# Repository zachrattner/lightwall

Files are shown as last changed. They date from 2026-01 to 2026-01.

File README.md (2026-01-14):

# Lightwall: An Installation That Sees You

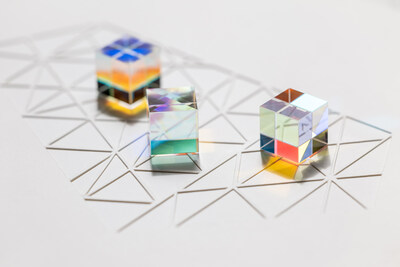
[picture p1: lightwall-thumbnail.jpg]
Lightwall


# Introduction
Created by artist [Rita Sus](https://emit-light.com), technologist [Zach Rattner](https://zachrattner.com), and students from [California State Fullerton](https://www.fullerton.edu/), Lightwall places the visitor at the center of the artwork's unfolding behavior. Rather than generating images or automating creativity, the piece uses AI as an expressive instrument: one that senses, reacts, and performs in the room.

Built from rotating prisms, custom electronics, and precisely controlled lighting, Lightwall transforms motion and speech into evolving patterns of color and sound. Inside the structure, more than a dozen microcontrollers coordinate sensors, prisms, motors, and sound cues, all synchronized with a live AI system running locally on a single Mac mini. This compact but powerful architecture allows the installation to observe, interpret, and respond instantly, producing an encounter that feels less like digital technology and more like a sensitive, perceptive presence.

# Running Lightwall

## Install base software packages
1. Install Homebrew: https://brew.sh/
2. Download ollama: https://ollama.com/download/mac
3. Download [XCode](http://apps.apple.com/us/app/xcode/id497799835) from App Store
4. `xcode-select --install` 

## Setup environment
```zsh
./setup-env.sh
./setup-llm-server.sh
./setup-speech-recognizer.sh
```

### Run main process
```zsh
./run.sh
```

### To start automatically on boot
1. In Settings on your Mac, turn on `Start up automatically after a power failure`
2. Also in Settings, turn on automatic logic for the Lightwall user
3. Finally, in Settings, add the Lightwall.app automator workflow to the login items

This will allow the Lightwall program to run automatically when you plug the device into power. 

# The Lightwall Collective
Thank you to everyone who helped make Lightwall possible.

## Lead Artist
- [Rita Sus](https://emit-light.com)

## Technical Director
- [Zach Rattner](https://zachrattner.com)

## Engineering and Development
- Akshat Sureshbhai Desai
- Austin Nguyen
- Christian Aaron Marshall
- Dr. Christopher Ryu
- Dylan Michael Geraci
- Edmarck Osmin Sosa Pineda
- Jake Estrada
- Jose Rodrigo Aguilar García
- Harry Le
- Steven Joseph Burroughs
- Uyen Hoang Thuc Tran

## Fabrication
- [Art & Framing Solutions](https://www.artandframingsolutions.com/)

## Assembly
- Hope Rattner
- Zeke Rattner

# License
[MIT License](https://github.com/zachrattner/lightwall/blob/main/LICENSE)

# Copyright
© 2026 Worthwhile Adventures LLC

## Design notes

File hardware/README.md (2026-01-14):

# Lightwall Hardware

This directory contains the hardware specifications, 3D models, and Bill of Materials (BOM) for the Lightwall project.

## Overview

The Lightwall is powered by an Apple Mac mini (M4 Pro) which coordinates 14 white dimmable LEDs and 12 prisms mounted on motors. The system uses a suite of Arduino Nano Every controllers for localized motor and LED control, with an Arduino Uno R4 WiFi for the radar sensor. The baud rate on the radar sensor is too fast for the Nano Every, hence the Uno. The sensors to the outside world are the radar sensor and a high-fidelity microphone. The Mac mini is mounted on a custom-built wooden frame, and the piece has no visible electronics.

## Bill of Materials (BOM)

| Part | Quantity |
| :--- | :--- |
| [#8 x 1/2" Wood Screws, Black, 400 Pcs](https://www.amazon.com/dp/B0BFL62Q2Q) | 1 |
| [12 VDC Power Supply](https://www.amazon.com/dp/B07GFC4VR3) | 2 |
| [5 VDC Power Supply](https://www.amazon.com/dp/B08744HB1X) | 2 |
| [5-Port USB Hub](https://www.amazon.com/dp/B0F5HSNDXF) | 5 |
| [AC Power Splitter](https://www.amazon.com/dp/B09K3R626Z) | 1 |
| [Arduino Nano Every](https://store-usa.arduino.cc/products/nano-every-with-headers) | 15 |
| [Arduino Nano Every Screw Mount](https://www.amazon.com/dp/B096XSH1D7) | 15 |
| [Arduino Uno R4 WiFi](https://store-usa.arduino.cc/products/uno-r4-wifi) | 1 |
| [Barrel Jack Power Extender - 3 ft](https://www.amazon.com/dp/B01N3WCHG5) | 26 |
| [Barrel Jack Splitter - 8 Way](https://www.amazon.com/dp/B0DBD5R98B) | 4 |
| [Constant Current Driver for LED](https://www.amazon.com/dp/B0C2ZXXTSD) | 12 |
| [Double-Sided Tape](https://www.amazon.com/dp/B0035LXTYU) | 1 |
| [Extension Cord - 6 ft, White](https://www.amazon.com/dp/B076K93FC4) | 1 |
| [Foam Core Board, 43 x 63 Inches](https://www.dickblick.com/products/white-foam-board/) | 1 |
| [Grounding Bar](https://www.amazon.com/dp/B0BWH6BC45) | 12 |
| [Heat Sink for LEDs](https://www.amazon.com/dp/B0DJK5B5L8) | 12 |
| [Heat Sink for Stepper Motor (4 per Motor)](https://www.amazon.com/dp/B0CFKGHWKZ) | 48 |
| [Hookup Wire Kit - 25 ft](https://www.amazon.com/dp/B0DNQC9HMV) | 2 |
| [LED Lens - 5 Degrees](https://www.amazon.com/dp/B0DRNBCHN7) | 12 |
| [LED Lens Holder](https://www.amazon.com/dp/B00LWU07FK) | 12 |
| [Logitech Blue Yeti Nano USB Microphone](https://www.amazon.com/dp/B07QLNYBG9) | 1 |
| [Mac mini - Apple M4 Pro Chip](https://www.apple.com/shop/buy-mac/mac-mini/apple-m4-pro-chip-with-12-core-cpu-16-core-gpu-24gb-memory-512gb) | 1 |
| [Mac Mini Mounting Bracket](https://www.amazon.com/dp/B0DPHLT5FH) | 1 |
| [Magnet Pairs](https://www.amazon.com/dp/B072KDBJWC) | 2 |
| [Natural White Watercolor Paper - Hot Press](https://www.dickblick.com/items/arches-natural-white-watercolor-paper-44-12-x-10-yds-hot-press-roll/) | 1 |
| [Optical Beam Splitter, 25mm Cube](https://www.amazon.com/dp/B0B1LJPMD7) | 12 |
| [Plastic Hanger Strap - 100 ft](https://www.amazon.com/dp/B0DNFBYVGL) | 1 |
| [Post Mount for Optical Beam Splitter](Prism%20Collar%20-%20Rectangular%20-%20Platter.stl) | 12 |
| [Rd-03D Radar Sensor](https://www.amazon.com/dp/B0D3CXVCFK) | 1 |
| [Set Screws - M4x4mm, 100 Pack](https://www.amazon.com/dp/B01N76F56R) | 1 |
| [Stepper Motor](https://www.sparkfun.com/stepper-motor-32-oz-in-200-steps-rev-1200mm-wire.html) | 12 |
| [Stepper Motor Driver Board](https://www.sparkfun.com/sparkfun-prodriver-stepper-motor-driver-tc78h670ftg.html) | 12 |
| [Thermal Glue](https://www.amazon.com/dp/B072MSXHJD) | 1 |
| [USB C Power Brick - 60W](https://www.amazon.com/dp/B0CYZ52VPX) | 2 |
| [USB C to C Cable - 6.6 ft](https://www.amazon.com/dp/B08D6NCQ1Z) | 5 |
| [USB C to Micro B Cable - 6 ft](https://www.amazon.com/dp/B09P13V1W8) | 16 |
| [White LED, 200 Lumen, 3W, 5V](https://www.amazon.com/dp/B092R3CQVX) | 12 |
| Wood Case | 1 |

## Fabrication

The `hardware` folder contains 3D models used for the assembly:
- [Lightwall.skp](Lightwall.skp): SketchUp model of the full assembly
- [Lightwall.stl](Lightwall.stl): STL model of the full assembly
- [Prism Collar - Rectangular - Platter.stl](Prism%20Collar%20-%20Rectangular%20-%20Platter.stl): Post mount for the optical beam splitters. Ordered from [Shapeways](https://www.shapeways.com/materials/pa12)
- [Board Mapping.jpg](Board%20Mapping.jpg): Physical diagram of the Arduino boards mapping to the stepper motor and LED drivers

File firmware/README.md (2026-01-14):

# Lightwall Firmware

This directory contains the source code and configuration for the microcontrollers that drive the Lightwall's physical components. These sketches are deployed to a network of Arduinos connected via USB to the Mac mini.

## Architecture

The system uses a distributed control architecture:
- **Arduino Nano Every**: Handles localized control of stepper motors and LED drivers.
- **Arduino Uno R4 WiFi**: Serves as the interface for the high-speed radar sensor.

## Libraries

The `libraries/` folder contains the necessary dependencies for the firmware. Notably:
- **RD03D**: This library is used to interface with the mmWave radar sensor. It comes from [Core Electronics](https://core-electronics.com.au/guides/detect-and-track-humans-with-mmwave-radar-on-an-arduino/).

## Hardware Mapping (`hwMap.json`)

The `hwMap.json` file is a critical component of the control system. It defines the mapping between the **logical address space** (how the software addresses a specific prism or LED) and the **physical devices** (which USB port and which specific Arduino pin corresponds to that hardware).

This mapping allows the Mac mini to send high-level commands to logical assemblies without needing to know the specific wiring details, making the system easier to maintain and reconfigure.

## Board Deployment

Each subdirectory in `boards/` corresponds to a specific physical controller in the installation.

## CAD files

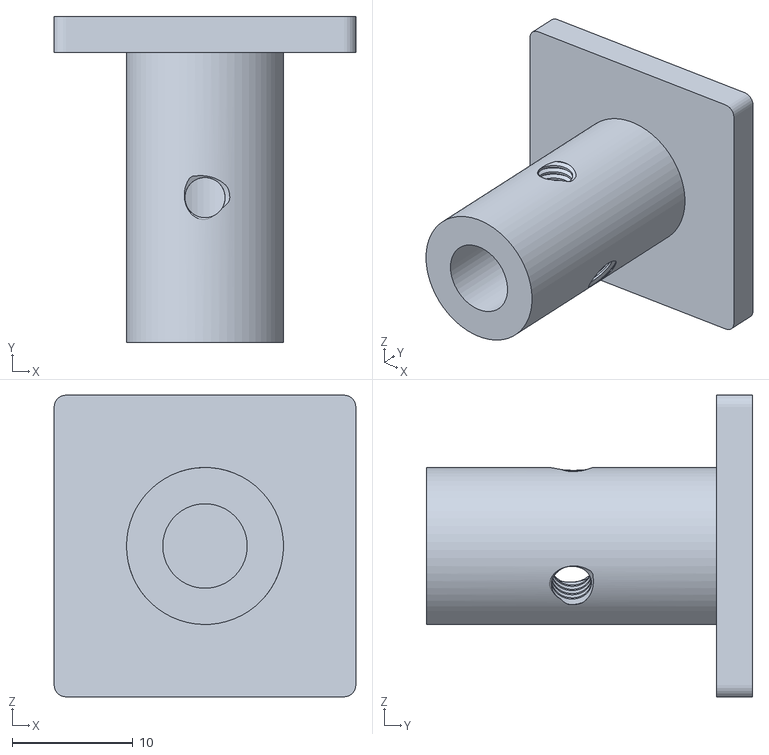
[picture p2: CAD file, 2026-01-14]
hardware/Prism Collar - Rectangular - Platter.stl
25.0 x 27.0 x 25.0

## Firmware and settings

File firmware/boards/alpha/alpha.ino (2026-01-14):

#include <Arduino.h>
#include "SparkFun_ProDriver_TC78H670FTG_Arduino_Library.h"
#include <avr/io.h>
#include <avr/interrupt.h>

// Wiring (SparkFun defaults):
//   D8  -> STBY  (active HIGH to run; LOW = standby)
//   D7  -> EN    (active HIGH enable)
//   D6  -> MODE0
//   D5  -> MODE1 (also SET_EN in variable mode; we keep fixed mode here)
//   D4  -> MODE2 (CLK)
//   D3  -> MODE3 (CW/CCW)
//   D2  -> ERR   (active LOW)
// Provide motor VM power per board docs. Set hardware slide switch to USER.

#define COMMAND_READY_SEQUENCE   "READY"
#define SERIAL_BAUD_RATE         115200
#define BOOTUP_DELAY_MS          2000
#define NAME_BUFFER_SIZE         8
#define DATA_TIMEOUT_MS          1000 
#define COMMAND_BUFFER_SIZE      64

static const char name[NAME_BUFFER_SIZE] = "ALPHA";
static char cmd_buf[COMMAND_BUFFER_SIZE];

static bool	   is_serial_overflow = false;
static char	   cmd_current_byte   = NULL;
static uint8_t cmd_len            = 0;

// Limit power consumption by capping current
#define MOTOR_CURRENT_LIMIT 64

// Motor parameters
// Driver board: https://www.sparkfun.com/sparkfun-prodriver-stepper-motor-driver-tc78h670ftg.html
// Motor: https://www.sparkfun.com/stepper-motor-32-oz-in-200-steps-rev-1200mm-wire.html
#define BASE_FULL_STEPS_PER_ROTATION 200
#define MICROSTEP_FACTOR 1
#define STEPS_PER_ROTATION (BASE_FULL_STEPS_PER_ROTATION * MICROSTEP_FACTOR)

#define ACTION_NAME_STR     "NAME"
#define ACTION_ROTATE_STR   "ROT"
#define ACTION_STEP_STR     "STP"
#define ACTION_POSITION_STR "POS"
#define ACTION_STOP_STR     "STOP"

typedef enum {
  ACTION_NAME,
  ACTION_ROTATE,
  ACTION_STEP,
  ACTION_POSITION,
  ACTION_STOP,
  ACTION_INVALID = 0xff
} action_t;

#define DIRECTION_CW_STR  "CW"
#define DIRECTION_CCW_STR "CCW"

typedef enum {
  DIRECTION_CW,
  DIRECTION_CCW,
  DIRECTION_INVALID = 0xff
} direction_t;

typedef struct {
  action_t     action;
  direction_t  direction;
  unsigned int arg1;
  unsigned int arg2;
} serial_cmd_t;

static serial_cmd_t serial_cmd;

typedef enum {
  MOTION_NONE,
  MOTION_ROTATE_CONTINUOUS,
  MOTION_STEP_FINITE
} motion_mode_t;

static volatile motion_mode_t g_motion_mode           = MOTION_NONE;
static volatile direction_t   g_motion_direction      = DIRECTION_CW;
static volatile uint32_t      g_motion_steps_remaining = 0;
static volatile uint16_t      g_step_interval_ms      = 0;   // ms between steps
static volatile uint16_t      g_step_elapsed_ms       = 0;   // ms accumulated since last step
static volatile uint16_t      g_current_position_steps = 0;   // 0..STEPS_PER_ROTATION-1

PRODRIVER motor_driver;

static action_t parse_action_token(const String &tok) {
  if (tok.equalsIgnoreCase(ACTION_NAME_STR)) {
    return ACTION_NAME;
  }
  if (tok.equalsIgnoreCase(ACTION_ROTATE_STR)) {
    return ACTION_ROTATE;
  }
  if (tok.equalsIgnoreCase(ACTION_STEP_STR)) {
    return ACTION_STEP;
  }
  if (tok.equalsIgnoreCase(ACTION_POSITION_STR)) {
    return ACTION_POSITION;
  }
  if (tok.equalsIgnoreCase(ACTION_STOP_STR)) {
    return ACTION_STOP;
  }
  return ACTION_INVALID;
}

static direction_t parse_direction_token(const String &tok) {
  if (tok.equalsIgnoreCase(DIRECTION_CW_STR)) {
    return DIRECTION_CW;
  }
  if (tok.equalsIgnoreCase(DIRECTION_CCW_STR)) {
    return DIRECTION_CCW;
  }
  return DIRECTION_INVALID;
}

bool parse_cmd(const String &line, serial_cmd_t* cmd) {
  cmd->action    = ACTION_INVALID;
  cmd->direction = DIRECTION_INVALID;
  cmd->arg1      = 0;
  cmd->arg2      = 0;

  String s = line;
  s.trim();

  if (s.length() == 0) {
    return false;
  }

  // action
  int p1 = s.indexOf(' ');
  if (p1 < 0) {
    String actionTok = s;
    actionTok.trim();
    cmd->action = parse_action_token(actionTok);
    return true;
  }

  String actionTok = s.substring(0, p1);
  actionTok.trim();
  cmd->action = parse_action_token(actionTok);

  s = s.substring(p1 + 1);
  s.trim();

  if (s.length() == 0) {
    return true;
  }

  // direction
  int p2 = s.indexOf(' ');
  if (p2 < 0) {
    String dirTok = s;
    dirTok.trim();
    cmd->direction = parse_direction_token(dirTok);
    return true;
  }

  String dirTok = s.substring(0, p2);
  dirTok.trim();
  cmd->direction = parse_direction_token(dirTok);

  s = s.substring(p2 + 1);
  s.trim();

  if (s.length() == 0) {
    return true;
  }

  // arg1
  int p3 = s.indexOf(' ');
  if (p3 < 0) {
    cmd->arg1 = (unsigned int)s.toInt();
    return true;
  }

  String arg1Tok = s.substring(0, p3);
  arg1Tok.trim();
  cmd->arg1 = (unsigned int)arg1Tok.toInt();

  s = s.substring(p3 + 1);
  s.trim();

  if (s.length() == 0) {
    return true;
  }

  // arg2
  cmd->arg2 = (unsigned int)s.toInt();
  return true;
}

void setup() {
  Serial.begin(SERIAL_BAUD_RATE);
  uint32_t t0 = millis();
  while (!Serial && (millis() - t0 < BOOTUP_DELAY_MS)) { }

  memset(&serial_cmd, 0, sizeof(serial_cmd_t));
  memset(&cmd_buf, 0, COMMAND_BUFFER_SIZE);

  // Set up motor
  motor_driver.settings.controlMode        = PRODRIVER_MODE_SERIAL;
  motor_driver.settings.stepResolutionMode = PRODRIVER_STEP_RESOLUTION_FIXED_FULL;
  motor_driver.begin();
  motor_driver.setCurrentLimit(MOTOR_CURRENT_LIMIT);
  motor_driver.sendSerialCommand();

  // Configure TCB0 for a 1 kHz interrupt (1 ms tick) on the Nano Every
  TCB0.CTRLA = 0;                              // disable while configuring
  TCB0.CTRLB = TCB_CNTMODE_INT_gc;             // periodic interrupt mode
  TCB0.CCMP  = 7999;                           // 8000 counts at 8 MHz = 1 ms
  TCB0.INTFLAGS = TCB_CAPT_bm;                 // clear any pending interrupt
  TCB0.INTCTRL  = TCB_CAPT_bm;                 // enable interrupt
  TCB0.CTRLA    = TCB_CLKSEL_CLKDIV2_gc | TCB_ENABLE_bm; // 16 MHz / 2 = 8 MHz, enable

  // Signal readiness
  Serial.println(COMMAND_READY_SEQUENCE);
}

ISR(TCB0_INT_vect) {
  // Clear interrupt flag
  TCB0.INTFLAGS = TCB_CAPT_bm;

  if (g_motion_mode == MOTION_NONE) {
    return;
  }
  if (g_step_interval_ms == 0) {
    return;
  }

  // 1 ms has passed
  g_step_elapsed_ms++;
  if (g_step_elapsed_ms < g_step_interval_ms) {
    return;
  }
  g_step_elapsed_ms = 0;

  bool ccw_bit = (g_motion_direction == DIRECTION_CCW);

  // Issue one step via serial each tick when due
  motor_driver.stepSerial(1, ccw_bit, 0);

  // Update absolute position in steps (0..STEPS_PER_ROTATION-1)
  if (g_motion_direction == DIRECTION_CW) {
    uint16_t pos = g_current_position_steps + 1;
    if (pos >= STEPS_PER_ROTATION) {
      pos = 0;
    }
    g_current_position_steps = pos;
  } else if (g_motion_direction == DIRECTION_CCW) {
    uint16_t pos = g_current_position_steps;
    if (pos == 0) {
      pos = STEPS_PER_ROTATION - 1;
    } else {
      pos -= 1;
    }
    g_current_position_steps = pos;
  }

  if (g_motion_mode == MOTION_STEP_FINITE && g_motion_steps_remaining > 0) {
    g_motion_steps_remaining--;
    if (g_motion_steps_remaining == 0) {
      g_motion_mode = MOTION_NONE;
    }
  }
}

void handle_rotate_cmd(direction_t direction, unsigned int rpm) {
  if (rpm > 100) {
    rpm = 100;
  }
  if (rpm == 0) {
    return;
  }

  // steps per minute, then ms per step
  unsigned long steps_per_minute = (unsigned long)rpm * (unsigned long)STEPS_PER_ROTATION;
  if (steps_per_minute == 0) {
    return;
  }

  unsigned long ms_per_step = 60000UL / steps_per_minute; // 60 s * 1000 / steps_per_minute
  if (ms_per_step == 0) {
    ms_per_step = 1; // cap to fastest we can schedule
  }
  if (ms_per_step > 65535UL) {
    ms_per_step = 65535UL;
  }

  noInterrupts();
  g_motion_direction       = direction;
  g_motion_mode            = MOTION_ROTATE_CONTINUOUS;
  g_motion_steps_remaining = 0;           // unused for continuous
  g_step_interval_ms       = (uint16_t)ms_per_step;
  g_step_elapsed_ms        = 0;
  interrupts();
}

void handle_step_cmd(direction_t direction, unsigned int steps, unsigned int duration_ms) {
  if ((steps == 0) || (duration_ms == 0)) {
    return;
  }

  unsigned long ms_per_step = (unsigned long)duration_ms / (unsigned long)steps;
  if (ms_per_step == 0) {
    ms_per_step = 1; // at least 1 ms between steps
  }
  if (ms_per_step > 65535UL) {
    ms_per_step = 65535UL;
  }

  noInterrupts();
  g_motion_direction       = direction;
  g_motion_mode            = MOTION_STEP_FINITE;
  g_motion_steps_remaining = (uint32_t)steps;
  g_step_interval_ms       = (uint16_t)ms_per_step;
  g_step_elapsed_ms        = 0;
  interrupts();
}

void handle_position_cmd(direction_t direction, unsigned int position_deg, unsigned int duration_ms) {
  // Map degrees (0..359 etc.) to target step in [0, STEPS_PER_ROTATION-1]
  unsigned int deg = position_deg % 360u;
  unsigned int target_step = (unsigned long)deg * (unsigned long)STEPS_PER_ROTATION / 360ul;
  if (target_step >= STEPS_PER_ROTATION) {
    target_step = STEPS_PER_ROTATION - 1;
  }

  // Default direction if not specified
  direction_t dir = direction;
  if (dir == DIRECTION_INVALID) {
    dir = DIRECTION_CW;
  }

  // Snapshot current position atomically
  uint16_t current_step;
  noInterrupts();
  current_step = g_current_position_steps;
  interrupts();

  // Compute how many steps to move in the requested direction to reach target
  unsigned int steps_to_move = 0;
  if (dir == DIRECTION_CW) {
    if (target_step >= current_step) {
      steps_to_move = target_step - current_step;
    } else {
      steps_to_move = (STEPS_PER_ROTATION - current_step) + target_step;
    }
  } else { // DIRECTION_CCW
    if (current_step >= target_step) {
      steps_to_move = current_step - target_step;
    } else {
      steps_to_move = current_step + (STEPS_PER_ROTATION - target_step);
    }
  }

  if (steps_to_move == 0 || duration_ms == 0) {
    return; // already at position or no duration specified
  }

  handle_step_cmd(dir, steps_to_move, duration_ms);
}

void loop() {
  while (Serial.available() > 0) {
    cmd_current_byte = (char) Serial.read();

    // checks for end of command string
    if ((cmd_current_byte == '\n') || (cmd_current_byte == '\r')) {
      is_serial_overflow = false;
      if (cmd_len) {
        cmd_buf[cmd_len] = '\0';
        String cmd_str = String(cmd_buf);
        parse_cmd(cmd_str, &serial_cmd);

        switch (serial_cmd.action) {
          case ACTION_NAME:
            Serial.println(name);
            break;

          case ACTION_ROTATE:
            handle_rotate_cmd(serial_cmd.direction, serial_cmd.arg1);
            break;

          case ACTION_STEP:
            handle_step_cmd(serial_cmd.direction, serial_cmd.arg1, serial_cmd.arg2);
            break;

          case ACTION_POSITION:
            handle_position_cmd(serial_cmd.direction, serial_cmd.arg1, serial_cmd.arg2);
            break;

          case ACTION_STOP:
            noInterrupts();
            g_motion_mode            = MOTION_NONE;
            g_motion_steps_remaining = 0;
            g_step_interval_ms       = 0;
            g_step_elapsed_ms        = 0;
            interrupts();
            break;

          default:
            Serial.print("ERR: Unrecognized action: ");
            Serial.println(cmd_str);
        }
        cmd_len = 0;
      }
    }
    else {
      if (!is_serial_overflow) {
        if (cmd_len < sizeof(cmd_buf)-1) {
          cmd_buf[cmd_len++] = cmd_current_byte;
        }
        else {
          cmd_len = 0;
          is_serial_overflow = true;
          Serial.println("ERR: overflow");
        }
      }
      else {
        // fall here to bypass adding bytes to the buffer
        // until we set next EOL byte
        continue;
      }
    }
  }
}

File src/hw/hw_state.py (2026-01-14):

import threading
import os
import sys
import json
import time
import glob
import serial
from util.logger import info, warning, error
from hw.radar_reader import RadarReader


class HWState:
    """
    Singleton that stores global hardware state for Lightwall.

    Holds:
      • LED serial instances
      • Motor serial instances
      • Radar serial instance
      • Current interaction state machine (IDLE, APPROACHING, ENGAGED, LEAVING)
    """

    BAUD_RATE = 115200

    _instance = None
    _lock = threading.Lock()

    # Valid state machine labels
    IDLE = "IDLE"
    APPROACHING = "APPROACHING"
    ENGAGED = "ENGAGED"
    LEAVING = "LEAVING"

    def __new__(cls):
        with cls._lock:
            if cls._instance is None:
                cls._instance = super().__new__(cls)
                cls._instance._initialized = False
        return cls._instance

    def __init__(self):
        # Prevent __init__ from running twice
        if self._initialized:
            return

        # Storage for serial devices
        self.led_serials = {}       # dict[str, serial.Serial]
        self.motor_serials = {}     # dict[str, serial.Serial]
        self.radar_serial = None    # serial.Serial or None
        self.radar_reader = None    # RadarReader or None

        # Hardware map loaded from hwMap.json
        self.hw_map = []            # list[dict]

        # State machine
        self._state = HWState.IDLE

        self._initialized = True
        info("HWState initialized with state IDLE")

    def load_hw_map(self):
        """Load hwMap.json to understand the peripheral devices connected."""
        script_dir = os.path.dirname(os.path.dirname(os.path.abspath(__file__)))
        hw_map_path = os.path.join(script_dir, "hw", "hwMap.json")

        try:
            with open(hw_map_path, "r", encoding="utf-8") as f:
                self.hw_map = json.load(f)
        except FileNotFoundError:
            error(f"Could not find hwMap.json at {hw_map_path}")
            sys.exit(1)
        except json.JSONDecodeError as e:
            error(f"Failed to parse hwMap.json: {e}")
            sys.exit(1)

        if not isinstance(self.hw_map, list):
            error("hwMap.json must contain a top level JSON array")
            sys.exit(1)

        info(f"Loaded hwMap.json with {len(self.hw_map)} entries.")

    def connect_peripherals(self):
        """Probe all /dev/cu.usb* devices, send NAME, and update hw_map.

        Returns a dict mapping board_name -> open serial connection for
        light boards only.
        """
        info("Auto discovering boards")

        potential_ports = glob.glob("/dev/cu.usb*")
        if not potential_ports:
            error("No USB devices found matching /dev/cu.usb*")
            return {}

        info(f"Found {len(potential_ports)} candidate device(s). Probing...")

        board_serials = {}

        for port in potential_ports:
            info(f"Probing {port}...")
            try:
                s = serial.Serial(port, self.BAUD_RATE, timeout=2, write_timeout=1)
            except serial.SerialException as e:
                error(f"Failed to open {port}: {e}")
                continue
            except Exception as e:
                error(f"Unexpected error opening {port}: {e}")
                continue

            # Give the board a moment to boot and clear any noise
            time.sleep(2)
            s.reset_input_buffer()

            # Ask for NAME with clean timeout handling
            try:
                s.write(b"NAME\r\n")
            except serial.SerialTimeoutException as e:
                error(f"Write timeout when sending NAME to {port}: {e}")
                s.close()
                continue
            except Exception as e:
                error(f"Error sending NAME to {port}: {e}")
                s.close()
                continue

            try:
                response = s.readline().decode("ascii", errors="ignore").strip()
            except Exception as e:
                error(f"Error reading NAME response from {port}: {e}")
                s.close()
                continue

            if not response:
                warning(f"No NAME response from {port} (timeout or empty)")
                s.close()
                continue

            hw_entry = self.find_hw_entry_by_name(response)
            if hw_entry is None:
                warning(f"Unrecognized device. NAME='{response}' on {port}")
                s.close()
                continue

            # We have a known board. Update its port in the hw map.
            hw_entry["port"] = port

            info(
                f"Matched board '{response}' to {port} "
                f"(type={hw_entry.get('type', 'unknown')})"
            )

            device_type = hw_entry.get("type")

            if device_type == "light":
                board_serials[response] = s
                self.register_led_serial(response, s)
            elif device_type == "motor":
                board_serials[response] = s
                self.register_motor_serial(response, s)
            elif device_type == "radar":
                board_serials[response] = s
                self.register_radar_serial(response, s)
            else:
                warning(f"Unknown board type '{device_type}' for board '{response}'")
                s.close()

        # Log any boards from hwMap.json that did not get a port assigned
        missing = [e["board_name"] for e in self.hw_map if e.get("port") in (None, "")]
        if missing:
            warning("No connected devices found for boards: " + ", ".join(missing))

        if not board_serials:
            error("No valid light boards found. Exiting.")
            sys.exit(1)

        return board_serials
    
    def register_led_serial(self, name, ser):
        """Register a serial connection belonging to an LED controller board."""
        self.led_serials[name] = ser
        info(f"Registered LED serial '{name}'")

    def register_motor_serial(self, name, ser):
        """Register a serial connection for a motor controller board."""
        self.motor_serials[name] = ser
        info(f"Registered motor serial '{name}'")

    def register_radar_serial(self, name, ser):
        """Register the serial connection for the radar board."""
        self.radar_serial = ser
        info(f"Registered radar serial '{name}'")

    def start_monitoring_radar(self):
        """Create and start a RadarReader if a radar serial device is available."""
        if self.radar_serial is None:
            warning("start_monitoring_radar called but no radar serial is registered")
            return

        if self.radar_reader is not None:
            # Already created, just ensure it is running
            self.radar_reader.start()
            return

        self.radar_reader = RadarReader(self.radar_serial)
        self.radar_reader.start()
        info("Radar monitoring started")
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

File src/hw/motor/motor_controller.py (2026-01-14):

from __future__ import annotations

import serial
from typing import Dict
from .motor_state import MotorState, MotorAddress
from util.logger import info
import threading
import time

class MotorController:
    """Controller responsible for creating and managing all MotorState objects."""

    # Minimum interval between commands to any motor, in seconds.
    # This helps prevent overrunning the motor firmware with back-to-back
    # serial commands that are too close together.
    _MIN_CMD_INTERVAL = 0.1

    def __init__(self, hwmap: list, board_serials: Dict[str, serial.Serial]) -> None:
        self.motors: Dict[MotorAddress, MotorState] = {}
        self.board_serials = board_serials
        self._lock = threading.Lock()
        self._last_cmd_time = 0.0

        info("Initializing MotorController")

        for entry in hwmap:
            if entry.get("type") != "motor":
                continue

            board_name = entry["board_name"]
            address = entry["address"]

            if board_name not in self.board_serials:
                continue

            ser = self.board_serials[board_name]
            self.motors[address] = MotorState(address=address, ser=ser)
            info(f"Mapped motor {address} on {board_name}")

        info(f"MotorController initialized with {len(self.motors)} motors")

    def _throttle(self) -> None:
        """Ensure a minimum interval between motor commands."""
        now = time.monotonic()
        delta = now - self._last_cmd_time
        if delta < self._MIN_CMD_INTERVAL:
            sleep_time = self._MIN_CMD_INTERVAL - delta
            # Keep this log at info level for now so we can see when throttling occurs.
            info(f"MotorController: throttling commands for {sleep_time:.3f}s to respect min interval.")
            time.sleep(sleep_time)
        self._last_cmd_time = time.monotonic()

    def rotate(self, address: MotorAddress, direction: str, rpm: int) -> None:
        with self._lock:
            if address not in self.motors:
                raise KeyError(f"Unknown motor address: {address}")
            self._throttle()
            self.motors[address].rotate(direction, rpm)

    def move_to(self, address: MotorAddress, direction: str, position: int, duration_ms: int) -> None:
        with self._lock:
            if address not in self.motors:
                raise KeyError(f"Unknown motor address: {address}")
            self._throttle()
            self.motors[address].move_to(direction, position, duration_ms)

    def stop(self, address: MotorAddress) -> None:
        with self._lock:
            if address not in self.motors:
                raise KeyError(f"Unknown motor address: {address}")
            self._throttle()
            self.motors[address].stop()            

__all__ = ["MotorController"]

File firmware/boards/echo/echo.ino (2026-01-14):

// Nano Every (ATmega4809)
// 5-channel LED driver EN/PWM dimming for a white LED (active-low modules) using a fixed-rate 20 kHz software PWM carrier
// - ISR @ 20 kHz (TCB0 periodic)
// - 5-bit effective PWM (625 Hz visible PWM; ISR still 20 kHz)
// - Breathing: 10 ms per brightness step (0..255..0), reverses at endpoints
// - Direct port writes inside ISR (no digitalWrite in ISR)

#include <avr/io.h>
#include <avr/interrupt.h>
#include <Arduino.h>
#include <string.h>
#include <stdlib.h>

// board name
static const char name[8] = "ECHO";

// ---------------- Config ----------------
static const bool    ACTIVE_HIGH  = false;            // Set false for active-low LED driver EN/PWM (HIGH disables, LOW enables)
static const uint8_t LED_PINS[] = {3, 5, 6, 9, 11};   // Arduino pins wired to LED driver EN/PWM inputs
static const uint8_t NUM_LEDS     = sizeof(LED_PINS)/sizeof(LED_PINS[0]);

// Serial communication speed
static const uint32_t SERIAL_BAUD_RATE = 115200;

// 20 kHz carrier: 16 MHz / 20,000 = 800 counts
static const uint16_t TCB0_CMP = 800 - 1;

// Effective PWM resolution/frequency
// Keep 20 kHz ISR but use 5-bit software PWM so the visible PWM is 20 kHz / 32 = 625 Hz
static const uint8_t PWM_BITS = 5;                    // 5-bit (0..31)
static const uint8_t PWM_MAX  = (1u << PWM_BITS);     // 32
static const uint8_t PWM_MASK = PWM_MAX - 1;          // 0x1F
static const uint8_t MIN_DUTY5 = 1;                   // clamp tiny non-zero 8-bit duties to 1/32 so EN actually enables

// ---------------- State ----------------
volatile uint8_t duty[8];                 // duty per channel 0..255 (use first NUM_LEDS)
volatile uint8_t pwmPhase = 0;            // 0..31 (5-bit phase)

// Per-channel fade state (used by ISR every 1 ms)
volatile uint8_t  fade_start[8];        // starting brightness (0..255)
volatile uint8_t  fade_target[8];       // final brightness  (0..255)
volatile uint16_t fade_duration_ms[8];  // total ms (0 = immediate)
volatile uint16_t fade_elapsed_ms[8];   // ms elapsed so far
volatile int16_t  fade_step_q8[8];      // per-ms step in Q8.8 (signed)

// blink state for LEDs
volatile uint8_t  blink_active[NUM_LEDS];
volatile uint8_t  blink_original[NUM_LEDS];
volatile uint16_t blink_timer_ms[NUM_LEDS];

// Fast GPIO caches
volatile uint8_t* outReg[8];
uint8_t           bitMask[8];

// ISR-time 1 ms derivation: 20 kHz -> 20 ticks per ms
static const uint8_t TICKS_PER_MS = 20;

// non-blocking serial parser command buffer and variables
static bool	overflow = false;
static char	currentByte;
static char	cmdBuf[64];
static uint8_t	cmdLen = 0;

static void tcb0_init_20khz() {
  // Periodic interrupt mode
  TCB0.CTRLB = TCB_CNTMODE_INT_gc;
  TCB0.CCMP  = TCB0_CMP;
  TCB0.INTFLAGS = TCB_CAPT_bm;
  TCB0.INTCTRL  = TCB_CAPT_bm;
  // CLK/1 (16 MHz)
  TCB0.CTRLA = TCB_CLKSEL_CLKDIV1_gc | TCB_ENABLE_bm;
}

ISR(TCB0_INT_vect) {
  TCB0.INTFLAGS = TCB_CAPT_bm;

  // ----- 5-bit software PWM at 20 kHz carrier (625 Hz effective) -----
  uint8_t phase = pwmPhase;               // 0..31
  for (uint8_t i = 0; i < NUM_LEDS; ++i) {
    // Map 8-bit duty (0..255) to 5-bit (0..31); clamp very small non-zero duties so the LED driver reliably enables
    uint8_t d5 = duty[i] >> (8 - PWM_BITS); // fast divide
    if (d5 > 0 && d5 < MIN_DUTY5) d5 = MIN_DUTY5;

    bool on = (phase < d5);
    if (!ACTIVE_HIGH) on = !on;
    if (on)  *outReg[i] |=  bitMask[i];
    else     *outReg[i] &= ~bitMask[i];
  }
  // Wrap 0..31
  pwmPhase = (phase + 1) & PWM_MASK;

  // ----- Derive 1 ms and update brightness every 10 ms -----
  static uint8_t tick20 = 0;
  if (++tick20 >= TICKS_PER_MS) {
    tick20 = 0;

    for (uint8_t i = 0; i < NUM_LEDS; ++i) {
      uint16_t dur = fade_duration_ms[i];
      if (dur == 0) continue;   // no active fade

      uint16_t t = fade_elapsed_ms[i] + 1;
      fade_elapsed_ms[i] = t;

      int32_t vq8 = ((int32_t)fade_start[i] << 8) +
                    (int32_t)fade_step_q8[i] * (int32_t)t;
      int32_t v = vq8 >> 8;
      if (v < 0)   v = 0;
      if (v > 255) v = 255;
      duty[i] = (uint8_t)v;

      if (t >= dur) {
        duty[i] = fade_target[i];
        fade_duration_ms[i] = 0;
      }
    }

    for (uint8_t i = 0; i < NUM_LEDS; ++i) {
      if (blink_active[i]) {
        if (--blink_timer_ms[i] == 0) {
          duty[i] = blink_original[i];
        }
      }
    }
  }
}

static inline void schedule_fade(uint8_t idx, uint8_t target, uint16_t duration_ms) {
  if (idx >= NUM_LEDS) return;

  noInterrupts();

  uint8_t start = duty[idx];
  fade_start[idx]       = start;
  fade_target[idx]      = target;
  fade_elapsed_ms[idx]  = 0;
  fade_duration_ms[idx] = duration_ms;

  if (duration_ms == 0) {
    // Instant set
    duty[idx] = target;
    fade_step_q8[idx] = 0;
  } else {
    // Signed fixed-point step: ((target - start) << 8) / duration_ms
    int16_t delta = (int16_t)target - (int16_t)start;    // -255..+255
    fade_step_q8[idx] = (int16_t)(( (int32_t)delta << 8) / (int32_t)duration_ms);
  }

  interrupts();
}

static inline void blink_LED(uint8_t idx) {
  if (idx >= NUM_LEDS) return;

  noInterrupts();

  if (duty[idx] > 0) {
    blink_original[idx] = duty[idx];
    duty[idx] = 0;
  } else {
    blink_original[idx] = 0;
    duty[idx] = 255;
  }
  blink_timer_ms[idx] = 1000;  // duration in ms; currently fixed
  blink_active[idx] = 1;

  interrupts();
}
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
